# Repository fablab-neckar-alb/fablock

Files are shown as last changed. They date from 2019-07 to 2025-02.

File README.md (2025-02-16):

# Fablock

This is the software for a door-locking controller featuring a pin-pad for
authorization entry, a beep speaker for feedback, a motor locking/unlocking
 the door, two sensors detecting door closing and successful locking and
 a USART uplink to higher-level authentication logic living on a raspberry pi.

## Configurations

There are several instaces for this procect.
Configure the instance in the makefile:

* Upper
    This is the door to the bikeworkshop.
    Enable it by specifying CONFIG=UPPER
* Demo Board
    This is the configuration for the evaluation setup.
    Enable it by specifying CONFIG=DEMO
* Cellar
    This is the door to the Cellar door.
    Enable it by specifying CONFIG=CELLAR
* Social Room
    This is the placeholder for configuration for the Social Room.
    Enable it by specifying CONFIG=SOCIAL

## lockserver

Included is also the higher-level daemon in lockserver/ and the openscad files
 for the pin-pad casing.

## statustool

Small statustool that decodes the output from the serial port of the arduino

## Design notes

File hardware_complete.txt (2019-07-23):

pinpad:

  external wiring:

    *===* (pin header)
    |   | 
    |   +-------------------+
    |                       | 
    *=R2'=*=R3'=*=R4'===Rn'=* (female header / connector)

    Ri' = (0, 1k, 1.2k, 1.5k, 1.8k, 4.7k/2, 3.3k, 4.7k, 6.8k, 10k, 22k, 68k)

  internal wiring (4x3 daughter board):

    VCC-----*-Ru---+------+---+
                   |      |   |
                   Rm     |   |
                   |      |   |
    Pin_C4--*------+     ^Dz  *--Keypad_1(+)
                   |      |
                   C_pinp |
                   |      |
    GND-----*-Rd---+------+---*--Keypad_2(-)

    Ru     = 10k
    Rd     = 1k
    Rm     = 10k
    C_pinp = 2*220nF
    Dz     = 12V zener diode (better: 5.6V zener diode (TODO)),
    (everything in SMD parts except for Dz).

            +----+----+----+----+
            | *  |              |
            |GND Rd      Dz     |
            +----+----+-||-+----+
            | *       |      *  |
            |P_C4   C_pinp   K- |
            +----+-Rm-+----+----+
            | *  |       Dz  *  |
            |VCC Ru          K+ |
            +----+----+----+----+

main:

       Motor    Door Switch
    GND VDD PWM VCC-PIN-GND
     |   |   |   |   |   |
red ======================
cable
                            Keypad  Speaker Lock Switch
                            (+) (-) PIN GND PIN GND
                             |   |   |   |   |   |
yellow ===========================================
cable

Door_Switch Lock_Switch
     |          |
 C2--+      C3--+
     |          |
    C_sw       C_sw
     |          |
GND--+----------+

// B5---onboard LED circuit--GND

VCC---+--------------+
      |              |
      R_motor        C_sense
      |              |
  VDD-+----R_sense---+--------SENSE(C7)
      |
      Motor-------------------servo_pwm(C0)
      |
GND---+

C5----speaker---GND

VCC---C_vcc---GND

currently found a better zener diode:
  Keypad_1---<Dz'---Keypad_2

Dz' = 5.6V zener diode
R_motor = 5.6 Ohm
R_sense = 1.5 MOhm
C_sense = 0.47 uF
C_vcc = 470 uF

C_sw = 0.47 uF

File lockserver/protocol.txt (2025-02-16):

Communication with the lockserver:
send datagrams to /run/lockserver.sock with send()
if you want a reply, bind your socket first.

a message is a string, the first word of which is a command: "command args". Optionally terminated with a line feed.

Commands starting with a "." are processed by the daemon. Commands starting with a "!" are forwarded to the microcontroller.

The commands are (see $valid_request):
.register <events>...
  registers the sender for a list of event types. The registration times out after 1 hour. This request is idempotent.
  events:
    log_debug, log_notice, log_warning, log_error: get log messages
    W, R: get lines written to/read from the device
    challenge: get challenge messages
      a challenge consists of "0001", 4 salt digits and the user pin.
      The challenge message contains "challenge <salt> <userid>" for a valid
      challenge and "challenge FAIL" for an invalid challenge.

.unregister <events>...
  unregisters from the given events.

.baudrate <rate>
  changes the baudrate on server and device.

.close <requester>
  closes the door (forcefully) for <requester> subsystem.

.open <requester>
  opens the door (unconditionally) for <requester> subsystem.

.openfor <requester> <userid> <check_permission>
  opens the door for user <userid>, requested by subsystem <requester>.
  if <check_permission> is nonzero, the userid will be checked for
  existence and permission.
  replies with "openfor <userid> <valid>".
  <valid> is nonzero iff the request was fulfilled.

.pinentry <pin>
  simulates the entry of a pin.

.state
  requests the state of the door. The reply is "state <locked?1:0> <closed?1:0> <opening?2:closing?1:0> <status-info?2:succeeded?1:0>".

.reset_device
  resets the device.

(?<param>(?: \w+)*)$/;

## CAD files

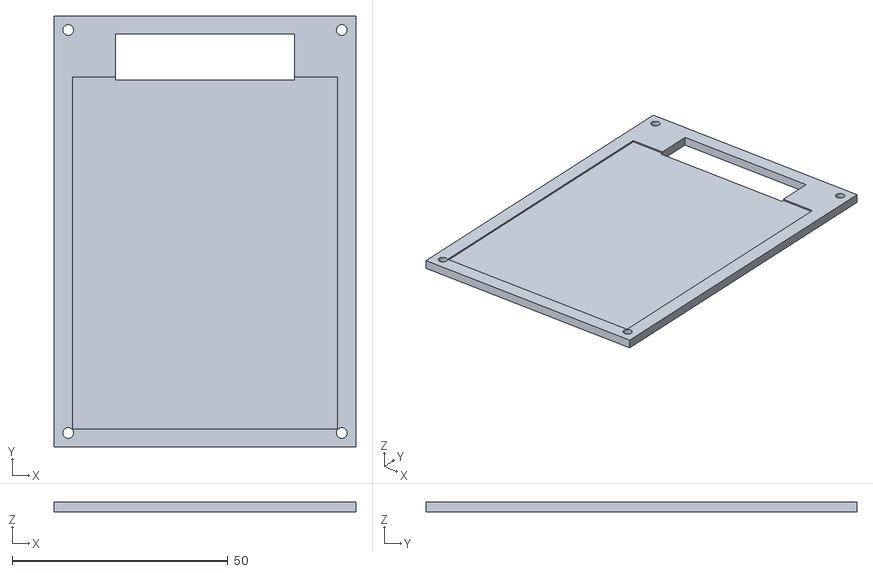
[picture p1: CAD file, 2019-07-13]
cad/pinpad-case-stl/rest.stl
70.0 x 100.0 x 2.40

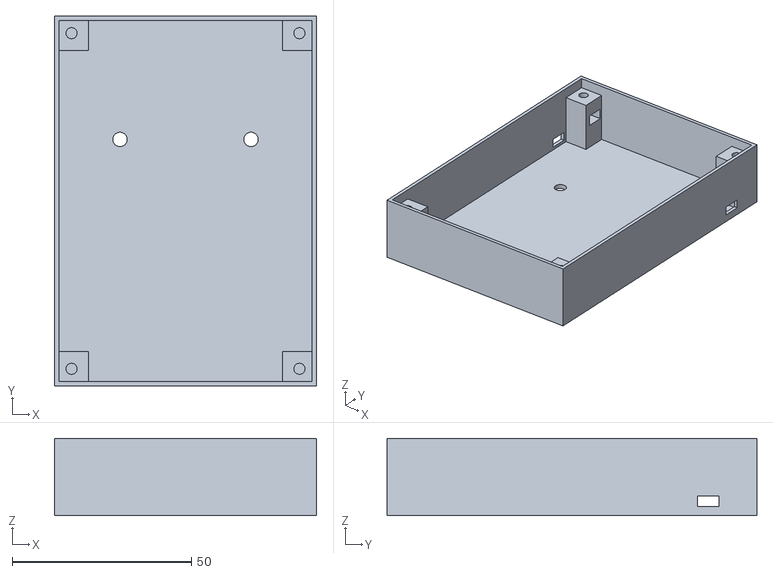
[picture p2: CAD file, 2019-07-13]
cad/pinpad-case-stl/box.stl
73.0 x 103.0 x 21.5

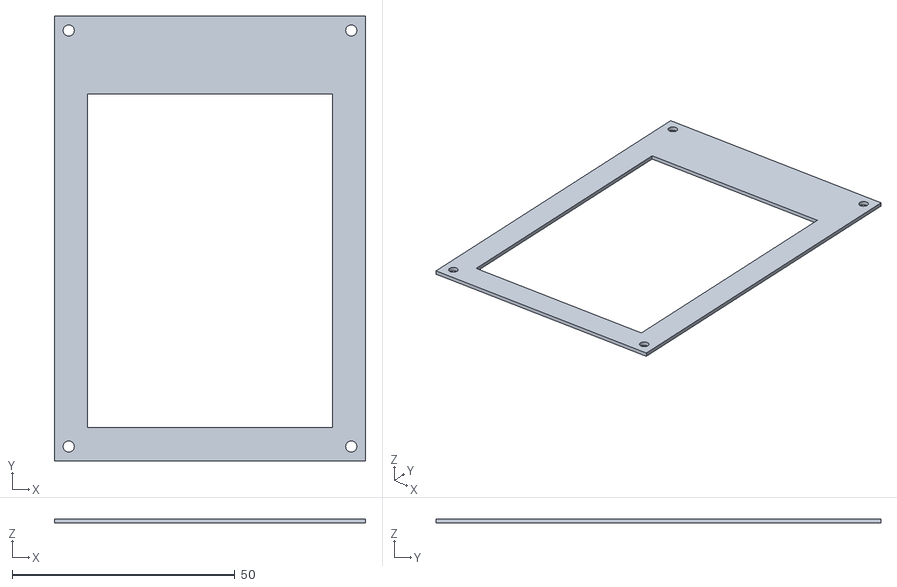
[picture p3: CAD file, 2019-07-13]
cad/pinpad-case-stl/lid.stl
70.0 x 100.0 x 1.00

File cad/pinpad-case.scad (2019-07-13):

include <utilities.scad>;

/*
  Copyright (c) 2019 by Thomas Kremer
  License: GNU GPL ver. 2 or 3
*/

/* PARTS LIST:
  box:  box();
  rest: rest();
  lid:  lid();
*/
demo = !currently_building;
hires = !demo;
$fn = hires ? 120 : 60;

pinpad_w = 61;
pinpad_h = 81;
pinpad_d = 0.4;
pinpad_bus_w = 41;
pinpad_bus_l_top = 10;
pinpad_bus_l = 51;
pinpad_border_w = 4;
pinpad_buttons_d = 2;

cable_r = 2;
cable_size = [6,3];

pinpad_x = 6;
pinpad_y = pinpad_x;
wall_d = 1.5;
bottom_d = wall_d;
lid_d = 1;
rest_d = 2;
box_d = 2*pinpad_bus_l_top+bottom_d;

box_size=[pinpad_w+2*pinpad_x,pinpad_h+2*pinpad_x+pinpad_bus_l_top,box_d];
  
lid_z = box_size[2]-lid_d;
pinpad_z = lid_z-pinpad_d;
rest_z = pinpad_z-rest_d;

// screw = [r, h, head_r, head_h]
screw = [2.5/2,18+1,5/2,1.5];
// nut = [w,h]
nut = [5,2+1]; // want extra space for nut because it's a bridging print.

box_screw_r = 4/2;

// align our screw boxes with the outside of the case.
// The screws are basically right outside the pinpad.
screw_box_w = (pinpad_x-screw[0])*2;

screws = [for (y=[-1,1],x=[-1,1])
            [box_size[0]/2,box_size[1]/2,0]+
            [x*box_size[0]/2,y*box_size[1]/2,atan2(0,x)]
            -screw_box_w/2*[x,y,0]];
//            -(pinpad_x-screw[0])*[x,y,0]];

box_screws = [for (x=[-1,1]) [(x+2)*box_size[0]/4,box_size[1]*2/3]];

// TODO: get the screw hole module into utilities.scad
module screw_hole(screw_r=3/2, screw_h=10, head_r=3, nut_w=5, nut_h=2, nut_z=2, depth=false, head_z=false, with_nut = false, screw=false, nut=false, infty = 100, extend=0, diaphragm_up=false, diaphragm_down=false, diaphragm_h = 0.3) {
  screw_r = screw != false ? screw[0] : screw_r;
  screw_h = screw != false ? screw[1] : screw_h;
  head_r = screw != false ? screw[2] : head_r;
  //head_h = screw != false ? screw[3] : head_h;
  nut_w = nut != false ? nut[0] : nut_w;
  nut_h = nut != false ? nut[1] : nut_h;
  with_nut = nut != false ? true : with_nut;

  //nut_z = depth != false ? nut_z+depth : nut_z;
  z = depth != false ? -depth : head_z != false ? head_z-screw_h : 0;
  nut_r = nut_w/sqrt(3);
  offs = extend;
  difference() {
    translate([0,0,z-offs])
      cylinder(r=screw_r+offs,h=screw_h+1);
    if (diaphragm_up) {
      translate([0,0,nut_z+nut_h+offs])
        cylinder(r=screw_r+offs+1,h=diaphragm_h);
    }
    if (diaphragm_down) {
      translate([0,0,nut_z-offs-diaphragm_h])
        cylinder(r=screw_r+offs+1,h=diaphragm_h);
      translate([0,0,z+screw_h-offs-diaphragm_h])
        cylinder(r=screw_r+offs+1,h=diaphragm_h);
    }
  }
  translate([0,0,z+screw_h-offs])
    cylinder(r=head_r+offs,h=infty-screw_h+2*offs);
  if (with_nut)
    translate([-nut_w/2,-nut_r,nut_z]-[1,1,1]*offs)
      cube([nut_w,nut_r+infty,nut_h]+[2,2,2]*offs);
}


module pinpad_hw() {
  eps = 0.01;
  color([0.7,0.7,0.7])
  linear_extrude(height=pinpad_d) {
    square([pinpad_w,pinpad_h]);
    translate([pinpad_w/2-pinpad_bus_w/2,pinpad_bus_l_top])
      square([pinpad_bus_w,pinpad_h]);
  }
  color([0.5,0.5,0.5])
  translate([pinpad_border_w,pinpad_border_w,eps])
    linear_extrude(height=pinpad_buttons_d-eps) {
      square([pinpad_w,pinpad_h]-[2,2]*pinpad_border_w);
  }
}

module box() {
  //screw_box_w = nut[0]+3*wall_d;//2*screw[0]+wall_d;
  //screw_box_w = screw_box_w+0.1;
  difference() {
    cube(box_size);
    difference() {
      translate([1,1,0]*(wall_d-slide_backlash)+[0,0,bottom_d])
        cube(box_size-[2,2,0]*(wall_d-slide_backlash));
      for (p2=screws,p=[[p2[0],p2[1],0]],ang=[p2[2]]) {
        difference() {
          translate(p-[1,1]*screw_box_w/2)
            cube([1,1,0]*screw_box_w+[0,0,rest_z]);
          translate(p)
            rotate([0,0,ang+90])
              screw_hole(screw=screw,nut=nut,head_z=box_size[2],nut_z=10,infty=50,diaphragm_up=true,extend=slide_backlash);
        }
      }
    }
    for (p=box_screws) {
      translate([p[0],p[1],-1])
        cylinder(r=box_screw_r,h=2+bottom_d);
    }
    translate([-1,box_size[1]-screw_box_w-cable_size[0]-1,bottom_d+1])
      cube([2+box_size[0],cable_size[0],cable_size[1]]);
    /*translate([-1,box_size[1]-screw_box_w-cable_r-1,bottom_d+cable_r+1])
      rotate([0,90,0])
        cylinder(r=cable_r,h=2+box_size[0]);*/
  }
}

module rest() {
  clearance = slide_backlash;
  union() {
    for (i=[0,1])
      linear_extrude(height=i?rest_d+pinpad_d:rest_d) difference() {
        square([box_size[0]-2*wall_d,box_size[1]-2*wall_d]);
        if (i)
          translate([1,1]*(pinpad_x-wall_d-clearance))
            square([pinpad_w,pinpad_h]+[2,2]*clearance);
        translate([pinpad_w/2-pinpad_bus_w/2,pinpad_h]+[1,1]*(pinpad_x-wall_d-clearance))
          square([pinpad_bus_w,pinpad_bus_l_top]+[2,2]*clearance);
        for (p2=screws,p=[[p2[0],p2[1]]]) {
          translate(p-[1,1]*wall_d)
            circle(screw[0]);
        }
      }
  }
}

module lid() {
  linear_extrude(height=lid_d) difference() {
    square([box_size[0]-2*wall_d,box_size[1]-2*wall_d]);
    translate([1,1]*(pinpad_x-wall_d+pinpad_border_w-1))
      square([pinpad_w,pinpad_h]-[2,2]*(pinpad_border_w-1));
    for (p2=screws,p=[[p2[0],p2[1]]]) {
      translate(p-[1,1]*wall_d)
        circle(screw[0]);
    }
  }
}

module case() {
  box();
  translate([wall_d,wall_d,rest_z])
    rest();
  translate([pinpad_x,pinpad_y,pinpad_z])
    pinpad_hw();
  translate([wall_d,wall_d,lid_z])
    lid();
}

if (demo) {
  //pinpad_hw();
  translate([-box_size[0]/2,-box_size[1]/2,0])
    case();
}

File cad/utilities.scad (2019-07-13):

/*
  Copyright (c) 2015-2017 by Thomas Kremer
  License: GNU GPL ver. 2 or 3
*/

no_virtuals = false;

// === fitting and friction avoiding constants ===

/*
  tests suggest the following:
  - cylinders of radii < 1 are fragile and easily broken.
  - the printer seems to constantly print 0.05mm more than specified, sometimes 0.1, sometimes even 0.0. (v=70mm/s, dz=0.2mm, T=220 deg, yellow filament TODO: diameter?)
  - consequently, holes are actually 2x0.05mm too small.
  - This also applies to vertical holes.
  - vertical axes in vertical holes are easily broken in assembly due to
     layered structure. But go smoothly.
  - 0.05 does no good. Maybe for hammering nails...
  - 0.1 sticks. Still need a hammer.
  - 0.15 sticks. Horizontal sliding possible. Vertical sliding sometimes difficult.
  - 0.2 fits and slides. Vertical sliding still a little rough.
  - 0.25 slides better.
  - gears go fine without backlash.
  - rafts are between a pain and impossible to remove.
  - small supports are also a pain to remove.
  - consider printing sliding gear axes horizontally (separately if necessary).
  - floating not measured. Consider one print layer (->0.2).
  - resting not measured. Consider half a print layer (->0.1) or postprocessing.
  - actually, printing 1mm radius holes stick well on 1mm radius real motors.
*/
rest_backlash  = 0.1;  // for accurately stacking objects onto each other
stick_backlash = 0.15; // for firmly sticking objects into holes
fit_backlash   = 0.25;  // for removably fitting objects into holes
slide_backlash = 0.3; // for objects gliding along other objects
float_backlash = 0.35;  // minimum distance for avoiding friction
gear_backlash  = 0.05;  // backlash for gears toward each other

/*
rest_backlash  = 0.1;  // for accurately stacking objects onto each other
stick_backlash = 0.15; // for firmly sticking objects into holes
fit_backlash   = 0.2;  // for removably fitting objects into holes
slide_backlash = 0.25; // for objects gliding along other objects
float_backlash = 0.3;  // minimum distance for avoiding friction
gear_backlash  = 0.0;  // backlash for gears toward each other
*/

amlaser_radius = 0.095; // radius of laser beam of laser cutter


// === for our external build system (used for e.g. splinecyl) ===

// the external build system will override this variable. To have code that
// checks it work outside of the build system, we need to initialize it.
currently_built_part = undef;
currently_building = currently_built_part != undef;

module part(name) {
  if (currently_built_part == name)
    children();
}

module demo() {
  if (!currently_building)
    children();
}

// === helper functions and constants ===

pi=3.1415926535897932384626433832795;
mat_2d_to_3d = [[1,0],[0,1],[0,0]];

function turn_matrix(v=[0,0,0],x=false,y=false,z=false) =
 x!=false?[[1,0,0],[0,cos(x),-sin(x)],[0,sin(x),cos(x)]]:
 y!=false?[[cos(y),0,sin(y)],[0,1,0],[-sin(y),0,cos(y)]]:
 z!=false?[[cos(z),-sin(z),0],[sin(z),cos(z),0],[0,0,1]]:
 turn_matrix(z=v[2])*
 turn_matrix(y=v[1])*
 turn_matrix(x=v[0]);

/*
    ^ w'
  -_ \  ^ v
    -_\/      
   <--+-_     
   w     -_
  w = m*v + n*w2, w2*v = 0
  w' = -m*v + n*w2 = w-2*m*v
  m*v = (v*w)/(|v|^2)*v = (v*w)/(v*v)*v
  w' = w-2*(v*w)/(v*v)*v
  M = id - v*v^t*2/(v*v) = id - [[v[0]],[v[1]],[v[2]]]*[v]*2/(v*v)
*/
function mirror_matrix(v=[0,0,1]) =
    [[1,0,0],[0,1,0],[0,0,1]] - [[v[0]],[v[1]],[v[2]]]*[v]*2/(v*v);

// normal,line vector, line source point (plane is in center)
// result is the intersection point.
// x: x*n = 0, x-p = m*v;
// (p+m*v)*n = 0; p*n + m*(v*n) = 0; m = -(p*n)/(v*n); (v*n != 0)
function plane_intersect(n,v,p) = p-(p*n)/(v*n)*v;

/*
  intersection of two circles:

 (x-gx_a)^2+y^2 = gsh_b^2, (x-g1_pos[0])^2+(y-g1_pos[1])^2 = gsh_a^2

  (x-x0)^2+(y-y0)^2 = r0^2,
  (x-x1)^2+(y-y1)^2 = r1^2

  (x-x0)^2-(x-x1)^2+(y-y0)^2-(y-y1)^2 = r0^2-r1^2,
  x0^2-x1^2-2x(x0-x1)+y0^2-y1^2-2y(y0-y1) = r0^2-r1^2,
  2x(x0-x1)+2y(y0-y1) = -r0^2+r1^2+x0^2+y0^2-x1^2-y1^2 = 2*C,
  y = (C-x(x0-x1))/(y0-y1),

  (x-x0)^2+((C-x(x0-x1))/(y0-y1)-y0)^2 = r0^2,
  x^2-2*x*x0+x0^2+(C^2-2Cx(x0-x1)+x^2(x0-x1)^2)/(y0-y1)^2-2*(C-x(x0-x1))/(y0-y1)*y0 + y0^2 = r0^2,
  x^2*(y0-y1)^2-2*x*x0*(y0-y1)^2+C^2-2Cx(x0-x1)+x^2(x0-x1)^2-2*(C-x(x0-x1))*(y0-y1)*y0 + (x0^2+y0^2-r0^2)*(y0-y1)^2 = 0,
  x^2*(y0-y1)^2 -2*x*x0*(y0-y1)^2 +C^2 -2Cx(x0-x1) +x^2(x0-x1)^2 -2*C*(y0-y1)*y0 +2*x(x0-x1)*(y0-y1)*y0 + (x0^2+y0^2-r0^2)*(y0-y1)^2 = 0,
  x^2*(y0-y1)^2 +x^2(x0-x1)^2 -2*x*x0*(y0-y1)^2 -2Cx(x0-x1) +2*x(x0-x1)*(y0-y1)*y0  +C^2 -2*C*(y0-y1)*y0 +(x0^2+y0^2-r0^2)*(y0-y1)^2 = 0,
  x^2*((y0-y1)^2+(x0-x1)^2) +x*(-2*x0*(y0-y1)^2 -2C(x0-x1) +2*(x0-x1)*(y0-y1)*y0)  +C^2 -2*C*(y0-y1)*y0 +(x0^2+y0^2-r0^2)*(y0-y1)^2 = 0,

  a = ((y0-y1)^2+(x0-x1)^2)
  b = 2*(-x0*(y0-y1)^2 -C(x0-x1) +(x0-x1)*(y0-y1)*y0)
  c = C^2 -2*C*(y0-y1)*y0 +(x0^2+y0^2-r0^2)*(y0-y1)^2,

  x = -b+-sqrt(b^2-4ac)/(2*a)

*/

function quadratic_solutions(a,b,c) =
  [(-b+sqrt(b*b-4*a*c))/(2*a),(-b-sqrt(b*b-4*a*c))/(2*a)];

function circles_intersections_helper2(x0,y0,r0,x1,y1,r1,C,x) =
  [[x[0],(C-x[0]*(x0-x1))/(y0-y1)],[x[1],(C-x[1]*(x0-x1))/(y0-y1)]];

function circles_intersections_helper(x0,y0,r0,x1,y1,r1,C) =
  circles_intersections_helper2(x0,y0,r0,x1,y1,r1,C,
    x = quadratic_solutions(
      a = (pow(y0-y1,2)+pow(x0-x1,2)),
      b = 2*(-x0*pow(y0-y1,2) -C*(x0-x1) +(x0-x1)*(y0-y1)*y0),
      c = pow(C,2) -2*C*(y0-y1)*y0 +(pow(x0,2)+pow(y0,2)-pow(r0,2))*pow(y0-y1,2)
    )
  );
function circles_intersections(p1,r1,p2,r2) =
  circles_intersections_helper(p1[0],p1[1],r1,p2[0],p2[1],r2,
    C = (p1*p1-p2*p2-r1*r1+r2*r2)/2
  );


function turn_to_vector(v,v3=false,v10=false,v11=false,v1=false,v2=false) =
  v3 == false ? turn_to_vector(v,v/norm(v)) :
  v10 == false ? turn_to_vector(v,v3,cross(v3,[0,0,1])) :
  v11 == false ? turn_to_vector(v,v3,v10,norm(v10) < 0.5 ? cross(v3,[0,1,0]) : v10) :
  v1 == false ? turn_to_vector(v,v3,v10,v11,v11/norm(v11)) :
  v2 == false ? turn_to_vector(v,v3,v10,v11,v1,cross(v1,v3)) :
    [[v1[0],v2[0],v3[0],0],
     [v1[1],v2[1],v3[1],0],
     [v1[2],v2[2],v3[2],0],
     [0,0,0,1]];


// === spline stuff ===

module cyl(p1=[0,0,0],p2=false,r=1,r1=false,r2=false,$fn=$fn) {
  two_point = p2!=false;
  p2 = two_point?p2-p1:p1;
  p1 = two_point?p1:[0,0,0];
  r1 = r1!=false?r1:r;
  r2 = r2!=false?r2:r;
  h = norm(p2);

  v3 = p2/norm(p2);
  v10 = cross(v3,[0,0,1]);
  v11 = norm(v10) < 0.5 ? cross(v3,[0,1,0]) : v10; // norm==sin(v3,e3)
  // norm at least 1/2 now (could be squeezed to 1/sqrt(2))
  v1 = v11/norm(v11);
  v2 = cross(v1,v3);

  // needs to map e3 to p2 and be orthogonal.
  mat = [[v1[0],v2[0],v3[0],0],
         [v1[1],v2[1],v3[1],0],
         [v1[2],v2[2],v3[2],0],
         [0,0,0,1]];

  translate(p1)
    multmatrix(mat)
      cylinder(r1=r1,r2=r2,h=h,$fn=$fn);
}

// c is an array of 4 control points, 0 <= t <= 1. dc and d2c are internal.
function bezier_eval(c,t,dc=false,d2c=false) = 
  dc == false ? bezier_eval(c,t,
    [c[0]*(1-t)+c[1]*t,c[1]*(1-t)+c[2]*t,c[2]*(1-t)+c[3]*t]) :
  d2c == false ? bezier_eval(c,t,dc,
    [dc[0]*(1-t)+dc[1]*t,dc[1]*(1-t)+dc[2]*t]) :
  d2c[0]*(1-t)+d2c[1]*t;  

// spline is an array of 3*N+1 control points, t arbitrary. ix is internal.
function bezier_spline_eval(spline,t,ix=false) = 
  ix == false ?
    t <= 0 ? spline[0] :
    t >= floor((len(spline)-1)/3) ? spline[len(spline)-1] :
    bezier_spline_eval(spline,t-floor(t),floor(t)*3) :
  bezier_eval([spline[ix],spline[ix+1],spline[ix+2],spline[ix+3]],t);

// cylinder from p1 to p2, cut to fit cylinders from p0 to p1 and p2 to p3.
// needed for polycyl and splinecyl.
// In extreme cases, a sphere part is injected. (extreme = angles above 20 deg)
module polycyl_part(p0,p1,p2,p3,r) {
  /*
     ______/    ______.
     _____/\    ___/-^
         /\ \     / /
           \     / /

    FIXED: a lot of nans.
  */
  r0 = len(p1) >= 4 ? p1[3]*r : r;
  r1 = len(p2) >= 4 ? p2[3]*r : r;
  p03 = [p0[0],p0[1],p0[2]];
  p13 = [p1[0],p1[1],p1[2]];
  p23 = [p2[0],p2[1],p2[2]];
  p33 = [p3[0],p3[1],p3[2]];
  p1 = p13;
  p2 = p23;
  at_start = p0 == false;
  at_end   = p3 == false;
  p0 = (p0 == false || p03 == p13) ? p1*2-p2 : p03;
  p3 = (p3 == false || p33 == p23) ? p2*2-p1 : p33;
  dp0 = p1-p0;
  dp  = p2-p1;
  dp1 = p3-p2;
  c0 = (dp0*dp)/(norm(dp0)*norm(dp));
  c1 = (dp*dp1)/(norm(dp)*norm(dp1));
  cosa = c0 > 0.99 ? 1 : c0;
  cosb = c1 > 0.99 ? 1 : c1;
  ds0 = min(norm(dp),norm(dp0))/4;
  ds1 = min(norm(dp),norm(dp1))/4;
/*
  a2 = acos(cosa)/2;
  b2 = acos(cosb)/2;
*/
  v0 = cross(dp0,dp)/(norm(dp0)*norm(dp));
  v1 = cross(dp,dp1)/(norm(dp)*norm(dp1));
  sina = norm(v0);
  sinb = norm(v1);
  a = cosa > 0.5 ? asin(sina) : acos(cosa);
  b = cosb > 0.5 ? asin(sinb) : acos(cosb);
/*
  a2 = asin(sina)/2;
  b2 = asin(sinb)/2;
*/
  a2 = a/2;
  b2 = b/2;
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

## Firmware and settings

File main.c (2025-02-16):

// for spi.h
#define NO_LUFA

#ifdef CONFIG_DEMO
  #include "demodoor.h"
#elif CONFIG_UPPER
  #include "oben.h"
#elif CONFIG_CELLAR
  #include "cellar.h"
#elif CONFIG_SOCIAL
  #include "sozialraum.h"
#else
  #error "Unset Config"
#endif

//#define DEBUG_DISPLAY
#define DEBUG_MOTOR_SENSE
//#define DEBUG_INTERRUPTS
#define ENABLE_EASTEREGGS
//#define ENABLE_COPYRIGHTED_EASTEREGGS


#include <avr/io.h>
#include <avr/sleep.h>
#include <avr/power.h>
#include <avr/wdt.h>
#include <util/atomic.h>
#include <util/delay.h>
#include <string.h>
#include <stdlib.h>
#include <stdbool.h>
#include <math.h>

#include <timers.h>
#define EVENT_QUEUE_SIZE 8
#include <events.c.h>


  
#define TIMER_DIV 1
#define TIMER_SCALE TIMER_SCALE_1
//#define TIMER_DIV 1024
//#define TIMER_SCALE TIMER_SCALE_DIV_1024

// was used for morse code:
#define shortdelay msec2ticks(200.0,TIMER_DIV)
#define longdelay msec2ticks(800.0,TIMER_DIV)

/*
#define EEPROMFS_VARS 2
#include "eeprom.h"
eepromfs_index_t eep_index;
*/
//#define eep_segment_low 0
//#define eep_segment_high 1

#define ledpin 5
#define baudrate 9600
//#define baudrate 57600
//#define baudrate 19200
// 9600 19200 38400 57600 115200

// can have baudrates of up to 2000000 (usable!)

// some defines used by the last LUFA project, parts of which were included.
#define LEDS_LED1 (1<<ledpin)
#define LEDs_ToggleLEDs(mask) PINB = mask
#define LEDs_GetLEDs() (PORTB & LEDS_LED1)
#define LEDs_TurnOnLEDs(mask) PORTB |= mask
#define LEDs_TurnOffLEDs(mask) PORTB &= ~mask
#define ATTR_NO_INIT __attribute__((section(".noinit")))
#define ATTR_ALWAYS_INLINE __attribute__((always_inline))

#define outbuf_size 80
#include <usart.h>

//#define ADCW_READ_COUNT (1 << 6)
#define ADCW_READ_COUNT (1 << 5)

#include <adc.h>
#include <adc_watch.h>
//#include "spi.h"
#include "prng.h"

#ifdef DEBUG_DISPLAY
#include <pcd8544_display.h>
#include "testfont.h"
#endif


#include "beep.h"
//#define MELODY_DEFINE_KOROBEINIKI
#include "melody.h"
#include "adnauseam.h"
#include "korobeiniki.h"

#ifdef ENABLE_COPYRIGHTED_EASTEREGGS
#include "la_prapoutische.h"
#include "mccarthys_waltz.h"
#endif

#include <pinpad.h>

//#define DOOR_MOTOR_IS_STEPPER
#define DOOR_MOTOR_IS_DC
#define DOOR_MOTOR_TIMER_DIV 64
#define DOOR_MOTOR_OC 0


#include "door.h"

/*

  note: space for bolt detector is 15 x 20 x 35 mm^3

  door layout:

  <---------- 140 ------------> 
   .........3......6...II....   ^
   .  +----------*-+----*-+ .   |
   .  |<--- 90 --->|      | .   |
   .  |            |      | .   110
   .  |            |      | .   |
   .  |        --- |      | 5   |
   ...|.....3... * |*.3...|..   v
      |            |   *  |


       Motor    Door Switch
    GND VDD PWM VCC-PIN-GND
     |   |   |   |   |   |
red ======================
cable
                            Keypad  Speaker Lock Switch
                            (+) (-) PIN GND PIN GND
                             |   |   |   |   |   |
yellow ===========================================
cable

*/

void process_char(char c);
void process_pinpad_char(char c);

static char hexchar(uint8_t i) {
  return i < 10 ? '0'+i : i < 16 ? 'A'-10+i : 'X';
}

void buftohex(const uint8_t* src, char* dest, int count) {
  for (int i = 0; i < count; i++) {
    uint8_t val = src[i];
    dest[2*i] = hexchar(val >> 4);
    dest[2*i+1] = hexchar(val & 15);
  }
  dest[2*count] = 0;
}

void inttohex(uint32_t value, char* dest, int count) {
  for (int i = 0; i < count; i++) {
    uint8_t val = (value & 0xf);
    value >>= 4;
    dest[count-1-i] = hexchar(val);
  }
  dest[count] = 0;
}

uint32_t hex2int(const char* s) {
  uint32_t res = 0;
  for (int i = 0; s[i] != 0 && i < 20; i++) {
    char c = s[i];
    char v = c-'0';
    if (v > 9) v = c-'A'+10;
    if (v > 15) v = c-'a'+10;
    if (v > 15 || v < 0) v = 0;
    res <<= 4;
    res |= v;
  }
  return res;
}

bool snprintl(char* s, int len, int32_t value) {
  bool positive = value >= 0;
  bool ok = 1;
  uint32_t val;
/*  if (!positive) {
    val = -value;
  }*/
  if (positive) {
    val = value;
  } else {
    val = (uint32_t)(-value);
  }
  int i = 0;
  while (i < len && val != 0) {
    char v0 = val % 10;
    val /= 10;
    s[len-1-i] = '0'+v0;
    i++;
  }
  if (i == 0) {
    s[len-1] = '0';
    i++;
  }
  if (!positive) {
    if (i == len-1) {
      i--;
      ok = 0;
    }
    s[len-1-i] = '-';
  }
  if (val != 0) {
    ok = 0;
  }
  while (i < len) {
    s[len-1-i] = ' ';
    i++;
  }
  return ok;
}

// --- power management ---

void poweroff() {
  cli();
  events_clear();
  PORTB &= ~(1<<ledpin);
  while(true) {
    // disable interrupts
    cli();
    // disable watchdog
    wdt_reset();
    MCUSR &= ~(1 << WDRF);
    wdt_disable();
    // disable Analog Comparator (to make sure that internal AREF is not used)
    ACSR = 1 << ACD;
    // disable ADC (ref. says "The ADC must be disabled before shutdown")
    // also disable all digital input buffers on ADC pins. Should happen
    // automatically anyway, but better to be explicit.
    adc_conf(false,0xff,0);
    // shut down all peripherals
    power_all_disable();
    // go to sleep
    set_sleep_mode(SLEEP_MODE_PWR_DOWN);
    sleep_enable();
    sleep_bod_disable();
    sleep_cpu();
    // should not be reached. But who knows for sure?
    PORTB |= 1<<ledpin; // If something wrong, at least notify the user...
  }
}

// --- application ---


// The device loads a saved state at bootup and maybe later again.
// It saves a state when requested by the user.
// Currently a no-op because we don't actually have any state.

void save_state() {
}

void load_state() {
}

// The LED is sadly placed on SCK, so we don't use it right now.
void led_blink_event(void* param) {
  LEDs_ToggleLEDs(LEDS_LED1);

  int16_t i = (int16_t)param;

  if (i > 0) {
    i--;
    enqueue_event_rel(msec2ticks(250,TIMER_DIV),&led_blink_event,(void*)i);
  }
}

/*
//void EVENT_beep_done() {
void EVENT_melody_done() {
  // nothing for now.
}
*/

void EVENT_softosc_done(uint8_t channel) {
  if (channel == BEEP_CHANNEL)
    EVENT_beep_done();
}


// we use a melody structure so that we can make more complicated feedback sounds in the future. However we must keep track of the starting notes' indexes in the index array below.
melody_begin(feedback_melody,480)
  // 0, sleep (0)
  melody_note(c,-1,1)
  melody_note(b,-2,1)
  melody_note(a,-2,8)
  melody_stopmarker()
  // 4, bad (1)
  melody_note(a,-1,4)
  melody_stopmarker()
  // 6, good (2)
  melody_note(a,0,4)
  melody_stopmarker()
  // 8, start (3)
  melody_note(a,1,4)
  melody_stopmarker()
  // 10, end (4)
  melody_note(e,1,4)
  melody_stopmarker()
  // 12, wakeup (5)
  melody_note(a,2,4)
  melody_stopmarker()
  // 14, good pin (6)
  melody_note(a,0,2)
  melody_note(cis,1,2)
  melody_note(e,1,2)
  melody_note(a,1,3)
  melody_note(e,1,1)
  melody_note(a,1,4)
  melody_stopmarker()
  // 21, bad pin (7)
  melody_note(g,-1,3)
  melody_rest(1)
  melody_note(g,-1,3)
  melody_rest(1)
  melody_note(g,-1,8)
  melody_stopmarker()
  // 27, anything else (8)
  melody_note(a,0,8)
melody_end()

// sleep, bad, good, start, end, wakeup, good pin, bad pin, anything
static const uint8_t feedback_notes_ix[] PROGMEM = {0,4,6,8,10,12,14,21,27};
#define feedback_sounds_count (sizeof(feedback_notes_ix)/sizeof(feedback_notes_ix[0]))


void do_pinpad_feedback(int i) {
  i = i < feedback_sounds_count ? i : feedback_sounds_count-1;
  //melody_play(feedback_melody);
  melody_set_time_unit(melody_get_time_unit(&feedback_melody));
  uint8_t ix = pgm_read_byte(&feedback_notes_ix[i]);
  melody_play_notes(melody_get_notes(&feedback_melody)+ix);
}

#define inbuf_size 80
char inbuf[inbuf_size+1];
int inbuf_len = 0;

// This is ok:
//char* const inbuf_ptr PROGMEM = &inbuf[0];
#define pinpad_inbuf_size 32
char pinpad_inbuf[pinpad_inbuf_size+1];
int pinpad_inbuf_len = 0;

#define pinpad_timeout sec2ticks(10,TIMER_DIV)
bool pinpad_sleeping = false;

void pinpad_sleep_event(void* param) {
  pinpad_sleeping = true;
  pinpad_sleep();
  pinpad_inbuf_len = 0;
  do_pinpad_feedback(0);
  usart_msg("AWAKE=0\n");
}

void pinpad_be_used() {
  dequeue_events(&pinpad_sleep_event);
  enqueue_event_rel(pinpad_timeout,&pinpad_sleep_event,(void*)0);
}

void print_door_feedback(uint8_t mode, uint8_t success) {
  /*
    DOOR=$locked$closed${closing?1:opening?2}$succeeded\n
    (succeeded == fail?0:success?1:unfinished?2:-)
  */
  /*
  char msg[10] = "DOOR=....\n";
  msg[5] = door_is_locked()?'1':'0';
  msg[6] = door_is_closed()?'1':'0';
  msg[7] = mode+'0';
  msg[8] = success?'1':'0';
  usart_write(msg,10);
  */
  usart_msg("DOOR=");
  usart_writechar(door_is_locked()?'1':'0');
  usart_writechar(door_is_closed()?'1':'0');
  usart_writechar('0'+mode);
  usart_writechar('0'+success);
  usart_writechar('\n');
}

#define DOOR_REPORT_DELAY msec2ticks(200,TIMER_DIV)

void report_state_event(void* param) {
  print_door_feedback(door_mode, 2);
}

uint8_t recent_pins[3] = {0,0,0};
//int32_t last_keypress_time = 0;

void EVENT_Interrupt(uint8_t port, uint8_t pins) {
  // fill the entropy into the random buffer:
  uint32_t time = get_time();
  prng_write_byte(time & 0xff);

  uint8_t changedpins = pins ^ recent_pins[port];

  uint8_t door_imask = (1 << DOOR_SENSOR_PIN) | (1 << DOOR_BOLTSENSOR_PIN);

  if (port == 1) { // Port C
    if (pinpad_sleeping && (~pins & (1<<PINPAD_PIN))) {
      pinpad_sleeping = false;
      pinpad_unsleep();
      pinpad_be_used();
      do_pinpad_feedback(5);
      usart_msg("AWAKE=1\n");
    }
    if (changedpins & door_imask) {
      if (changedpins & (1 << DOOR_SENSOR_PIN))
        door_sensor_changed();
      if (changedpins & (1 << DOOR_BOLTSENSOR_PIN))
        door_boltsensor_changed();
      //print_door_feedback(0,success);
      dequeue_events(&report_state_event);
      enqueue_event_rel(DOOR_REPORT_DELAY,&report_state_event,NULL);
    }
  }
/*
  //  D6,D7,B0,B1: button ports, input (up,right,left,down)
  uint8_t mask = port == 0 ? 0x03 : port == 2 ? 0xc0 : 0;
  changedpins &= mask;
*/

  recent_pins[port] = pins;

#ifdef DEBUG_INTERRUPTS
  char msg[10] = "r0=......\n";
  msg[1] = '0'+port;
  inttohex(pins,&msg[3],2);
  msg[5] = '\n';
  msg[6] = 0;
  if (usart_writable_space() > 7) {
    usart_write(msg,6);
  }
#endif
}

ISR (PCINT0_vect, ISR_BLOCK)
{
  EVENT_Interrupt(0,PINB);
}

ISR (PCINT1_vect, ISR_BLOCK)
{
  EVENT_Interrupt(1,PINC);
}

ISR (PCINT2_vect, ISR_BLOCK)
{
  EVENT_Interrupt(2,PIND);
}

void setup_Interrupts(uint8_t maskB, uint8_t maskC, uint8_t maskD) {
  PCICR = ((maskB?1:0) << PCIE0)
        | ((maskC?1:0) << PCIE1)
        | ((maskD?1:0) << PCIE2);
  // PCIFR & (1<< PCIF0)
  PCMSK0 = maskB;
  PCMSK1 = maskC;
  PCMSK2 = maskD;
}
 
void buttons_init() {
  // enable pull-ups for B0,B1,D6,D7
  //PORTB |= 0x03;
  //PORTD |= 0xc0;
  
  uint8_t door_imask = (1 << DOOR_SENSOR_PIN) | (1 << DOOR_BOLTSENSOR_PIN);
  //setup_Interrupts(0x03,(1<<PINPAD_PIN) | door_imask,0xc0); // B0,B1,D6,D7
  setup_Interrupts(0x00,(1<<PINPAD_PIN) | door_imask,0x00);

  recent_pins[0] = PINB;
  recent_pins[1] = PINC;
  recent_pins[2] = PIND;
}

const char ok_msg[] PROGMEM = "OK.\n";
#define usart_ok() usart_write_P(ok_msg,sizeof(ok_msg)-1)

#define pinpad_debug_interval msec2ticks(100,TIMER_DIV)
void pinpad_debug_event(void* param) {
  int16_t value = adcw_state.values[PINPAD_PIN];
  char msg[5];
  snprintl(msg,4,value);
  msg[4] = 0;
#ifdef DEBUG_DISPLAY
  display_text(0,24,&testfont,msg);
#else
  usart_writechar('P');
  usart_write(msg,4);
  usart_writechar('\n');
#endif
  enqueue_event_rel(pinpad_debug_interval,&pinpad_debug_event,NULL);
}

void process_line() {
  char *s = inbuf;
  if (inbuf_len == 0)
    return;
  if (s[0] != '!') {
    // int len = inbuf_len;
    // we don't have any use for non-command data, so we just remind the user
    // to disable the tty's useless echo feature.
    usart_msg("!ECHO OFF\n");
  } else if (inbuf_len >= 2) {
    char cmd = s[1];
    char *param = &s[2];
    switch (cmd) {
      case '0': {
          // our protocol version. May also be used as a generic ping.
          usart_msg("VERSION 3\n");
        }
        break;
      case 'a': {
          // start/stop adnauseam playing.
          uint32_t do_play = hex2int(param);
          if (do_play) {
            adnauseam_play(korobeiniki_progression);
          } else {
            adnauseam_stop();
          }
        }
        break;
      case 'b': {
          // set a new baud rate. The user will have to adapt to get the OK.
          uint32_t baud = hex2int(param);
          usart_init_baud(baud);
          usart_ok();
        }
        break;
      case 'D': {
          // open/close the door.
          uint32_t open = hex2int(param);
          if (open)
            door_unlock();
          else
            door_lock();
          usart_ok();
        }
        break;
      case 'd': {
        // get current door state.
        dequeue_events(&report_state_event);
        enqueue_event_rel(DOOR_REPORT_DELAY,&report_state_event,NULL);
      }
      case 'f': {
          // blink the LED <param> times.
          LEDs_TurnOffLEDs(LEDS_LED1);
          uint16_t count = hex2int(param)*2-1;
          enqueue_event_rel(1,&led_blink_event,(void*)count);
        }
        break;
      case 'F': {
          // stop blinking the LED.
          // turn it on (param=1) or off (param=0) or leave it as it is (param=2)
          uint16_t stay = hex2int(param);
          dequeue_events(&led_blink_event);
          if (stay == 0) {
            LEDs_TurnOffLEDs(LEDS_LED1);
          } else if (stay == 1) {
            LEDs_TurnOnLEDs(LEDS_LED1);
          }
        }
        break;
      case 'G': {
          // read adc_watch channel <param>.
          uint8_t num = hex2int(param);
          usart_write(inbuf,inbuf_len);
          uint32_t value;
          value = adcw_state.values[num % 8];
          char msg[10];
          inttohex(value,msg,9);
          usart_writechar(' ');
          usart_write(msg,9);
          usart_writechar('\n');
        }
        break;
      case 'k':
        // play the korobeiniki main theme once.
        melody_play(&korobeiniki_a);
        break;
      case 'l':
        // currently a no-op.
        load_state();
        usart_ok();
        break;
      case 'm': {
          // play musical feedback sound <param>.
          uint32_t i = hex2int(param);
          do_pinpad_feedback(i);
        }
        break;
      case 'P': {
          // debug the pinpad by printing out adc readings.
          enqueue_event_rel(pinpad_debug_interval,&pinpad_debug_event,NULL);
          usart_ok();
        }
        break;
      case 's':
        // currently a no-op.
        save_state();
        usart_ok();
        break;
      case 't': {
          // beep with frequency <param> for half a second.
          uint16_t freq = hex2int(param);
          beep(freq,500);
        }
        break;
      case 'T': {
          // Get (up-)time. Use to verify that a reset has been done.
          uint32_t time = get_time();
          usart_msg("TIME=");
          char msg[9];
          inttohex(time,msg,8);
          usart_write(msg,8);
          usart_writechar('\n');
        }
        break;
      case 'z':
        // power down.
        poweroff();
        break;
    }
  }
}

void process_char(char c) {
  if (c == 10 || c == 13) {
    if (inbuf_len < inbuf_size) {
      inbuf[inbuf_len] = 0;
      process_line();
    }
    inbuf_len = 0;
  } else if (inbuf_len < inbuf_size) {
    if (c > 0x80 || c < 0x20) {
      inbuf_len = inbuf_size;
    } else {
      inbuf[inbuf_len] = c;
      inbuf_len++;
    }
  } // else ignore more characters and in the end the whole line.
}

void process_pinpad_line() {
  char *s = pinpad_inbuf;
  if (pinpad_inbuf_len == 0)
    return;

  // special single-digit codes (*X#).
  if (pinpad_inbuf_len == 1) {

    switch (pinpad_inbuf[0]) {
      // code to just lock the door: *0#
      case '0' :
        door_lock();
        //door_schedule_locking(sec2ticks(2,TIMER_DIV));
        return;
#ifdef ENABLE_EASTEREGGS
      // code to start music: *1#
      case '1' :
            adnauseam_play(korobeiniki_progression);
            return;
      // code to stop music: *2#
      case '2':
            adnauseam_stop();
            return;
#ifdef ENABLE_COPYRIGHTED_EASTEREGGS
      case '3':
            melody_play(&la_prapoutische);
            return;
      case '4':
            melody_play(&mccarthys_waltz);
            return;
#endif
#endif
      default:;
    }
  }
#ifdef DEBUG_BACKDOOR
  #warning(Backdoor Active)
  // TODO: remove this backdoor:
  if (strcmp(s,"12345") == 0) {
    door_unlock();
  }
#endif

#ifdef DEBUG_DISPLAY
  display_clear();
  display_text(0,8,&testfont,s);
#endif
  usart_msg("PIN=");
  usart_write(s,pinpad_inbuf_len);
  usart_msg("\n");
}

// TODO: beep accordingly
void process_pinpad_char(char c) {
  if (c == '#') {
    if (pinpad_inbuf_len < pinpad_inbuf_size) {
      pinpad_inbuf[pinpad_inbuf_len] = 0;
      process_pinpad_line();
    }
    pinpad_inbuf_len = 0;
    do_pinpad_feedback(4);
  } else if (c == '*') {
    pinpad_inbuf_len = 0;
    do_pinpad_feedback(3);
  } else if (pinpad_inbuf_len < pinpad_inbuf_size) {
    if (c > 0x80 || c < 0x20) {
      pinpad_inbuf_len = pinpad_inbuf_size;
    } else {
      pinpad_inbuf[pinpad_inbuf_len] = c;
      pinpad_inbuf_len++;
#ifdef DEBUG_DISPLAY
      if (pinpad_inbuf_len < pinpad_inbuf_size) {
        pinpad_inbuf[pinpad_inbuf_len] = 0;
        display_text(0,16,&testfont,pinpad_inbuf);
      }
#endif
      do_pinpad_feedback(2);
    }
  } // else ignore more characters and in the end the whole line.
}

void EVENT_USART_Read(char c) {
  // fill the entropy into the random buffer:
  prng_write_byte(get_time() & 0xff);

  process_char(c);
}

void EVENT_pinpad_keypressed(char c) {
  // fill the entropy into the random buffer:
  prng_write_byte(get_time() & 0xff);

  pinpad_be_used();
  if (c != 0)
    process_pinpad_char(c);
  else do_pinpad_feedback(1);
}

void EVENT_adc_watch(uint8_t channel, int16_t value) {
  if (channel == PINPAD_PIN) {
    pinpad_on_adc_read(value);
  } else if (channel == DOOR_MOTOR_SENSE_PIN) {
    door_on_motor_sense_read(value);
#ifdef DEBUG_MOTOR_SENSE
    char s[5];
    snprintl(s,4,value);
    s[4] = '\n';
    usart_msg("SENSE=");
    usart_write(s,5);
#endif
  } else {
    adc_watch_set_range(channel,value-2,value+2);
  }
}

/*
  1 = stall (before succeeding in whatever we're doing)
  2 = not running, but should
  3 = running, but should not
*/

void EVENT_door_motor_failing(uint8_t symptom) {
  //char msg[] = "MFAIL=0\n";
  //msg[6] = '0'+symptom;
  //usart_write(msg,8);
  usart_msg("MFAIL=");
  usart_writechar('0'+symptom);
  usart_writechar('\n');
}

void EVENT_door_locked(bool success) {
  do_pinpad_feedback(success?5:0);
  print_door_feedback(1,success?1:0);
}

void EVENT_door_unlocked(bool success) {
  do_pinpad_feedback(success?4:1);
  print_door_feedback(2,success?1:0);
}

void EVENT_door_mode_changed(uint8_t old_mode) {
  dequeue_events(&report_state_event);
  enqueue_event_rel(DOOR_REPORT_DELAY,&report_state_event,NULL);
}


void startup() {
  // disable watchdog if enabled
  wdt_reset();
  MCUSR &= ~(1 << WDRF);
  wdt_disable ();

  // disable any output, just in case
  DDRB = 0;
  DDRC = 0;
  DDRD = 0;
  // enable pullups
  PORTB = 0xff;
  PORTC = 0xff;
  PORTD = 0xff;

  // configure pins
  PORTB &= ~(1<<ledpin);
  DDRB |= 1<<ledpin;

  //adc_conf(true,0,7); // enable, no adc pins, slow prescaler
  // spec says 50..200kHz for accuracy, we have 16M for cpu, need factor 2^7.

  // setup event processing
  events_start(TIMER_SCALE);

  usart_init();
  buttons_init();
  door_init();

  adc_conf(true,0,ADC_DIV_128); // pins C3, ADC6 and ADC7
  adc_watch_init(0);
  pinpad_init();

/*
  NONATOMIC_BLOCK(NONATOMIC_FORCEOFF) {
    eepromfs_index(&eep_index,0,0);
  }
*/

#ifdef DEBUG_DISPLAY
  display_init();
#endif
  adc_watch_start();

  load_state();
}

int main() {

  startup();
  prng_seed(0);
  //application_start(0); // starts default application (menu).

  sei();


  // prepare for sleeping
  set_sleep_mode(SLEEP_MODE_IDLE);
   // _ADC, _PWR_DOWN, _PWR_SAVE, _STANDBY, _EXT_STANDBY
   // PWR_SAVE leaves Timer2 active, PWR_DOWN is rather off.
  while(true) {
    // let the ISRs handle the events.
    sleep_mode();
      /* or:
           sleep_enable(); sei(); sleep_cpu(); sleep_disable();
         for avoiding race conditions we don't have.
      */
  }
  return 0;
}

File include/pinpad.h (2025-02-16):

/*

  Custom pinpad driver. Consumes 1 pin on Port C.

  Copyright (c) 2019 Thomas Kremer

*/

/*
 * This program is free software; you can redistribute it and/or modify it
 * under the terms of the GNU General Public License version 2 or 3 as
 * published by the Free Software Foundation.
 */

#ifndef __PINPAD_H__
#define __PINPAD_H__

/*
  This is the common implementation to read a pressed key on the pinpad pin.
  

  Requirements: 
    * A pin with both ADC and interrupt capability (C0..C5).
    * Choose one of the surrported pinpad models by defining
      PINPAD_IMPLEMENTATION to LINEAR or MATRIX            

  internal wiring:
    We used C = 2*220nF, Dz = 12V Zener diode, soldered everything directly
    between two pin headers (everything in SMD parts except for Dz).

  # S1: Adc Conection to Arduino input pin:

    VCC -----+
             Ru
             +-------+--- *K+
             Rm      |
    MC_adc---+      ^Dz
             C       |
             +-------+--- *K-
             Rd
    GND-*----+

    Chosen Values:
      R_u = 10k 
      R_d = 1k
      R_m can be ignored as there is no current flowing over the ADC
      R_k(i) = chosen in pinpad_matrix.h or pinpad_linear.h
      The pinpad adc value at the MC pin can be calculated with the formula:
      MC_adc(i) = 1024 * (R_k(i) + R_u) / (R_k(i) + R_ud)

    Derived Values:
      The adc of our arduino has 10bit Resolution.
      Adc_range = 2^10 = 1024
      Adc_max = 2^10 - 1 = 1023
*/

// every implementation of a pipad needs the function get_pinpad_key and the value pinpad_min_idle
#ifdef PINPAD_LINEAR
#include "pinpad_linear.h"
#else
#ifdef PINPAD_MATRIX
#include "pinpad_matrix.h"
#else
#error "PINPAD_IMPLEMENTATION was not set"
#endif
#endif
#include <adc_watch.h>

/* This needs to be done elsewhere:
void EVENT_adc_watch(uint8_t channel, int16_t value) {
  if (channel == PINPAD_PIN)
    pinpad_on_adc_read(value);
}
void init() {
  PCICR |= 1<<PCIE1;
}
*/

// Port is always C
#ifndef PINPAD_PIN
#define PINPAD_PIN 0 // C0, ADC0
#endif // PINPAD_PIN


/// @brief Pinpad context to trac the currently monitored value
typedef struct
{
  int16_t minval;
} pinpad_ctx_t;
pinpad_ctx_t pinpad_ctx;

void EVENT_pinpad_keypressed(char c);
bool snprintl(char *s, int len, int32_t value);
/**
 * @brief pressing a key i means going down to a voltage that is within
 *        pinpad_adc_values[i], then going up again.
 * @param value todo
 */
void pinpad_on_adc_read(int16_t value)
{
  // Get the tracked value
  int16_t minval = pinpad_ctx.minval;
  // Was the value reset then start a new measurement with the current value
  if (minval == 1024)
  {
    // TODO:
    adc_watch_set_range(PINPAD_PIN, value - 5, value + 5);
  }
  // Update the tracked value if the value if it is lower
  if (value < minval)
  {
    minval = value;
    pinpad_ctx.minval = minval;
  }
  // Once the key has been released
  if (value > pinpad_min_idle)
  {
    char key = get_pinpad_key(minval);
    if(key != '\0'){
        EVENT_pinpad_keypressed(key);
    }
    // Reset traced value and adc watch range
    pinpad_ctx.minval = 1024;
    adc_watch_set_range(PINPAD_PIN, pinpad_max_valid, 1023);
  }
}

void pinpad_sleep()
{
  // need to activate digital input, disable reading
  uint8_t mask = (1 << PINPAD_PIN);
  PCMSK1 |= mask;
  DIDR0 &= ~mask;
  adc_watch_set_mask(adcw_state.mask & ~mask);
  // adc_watch_set_range(PINPAD_PIN,0,1023);
}

void pinpad_unsleep()
{
  // need to disable digital input, activate reading
  uint8_t mask = (1 << PINPAD_PIN);
  PCMSK1 &= ~mask;
  DIDR0 |= mask;

  adc_watch_set_range(PINPAD_PIN, pinpad_max_valid, 1023);
  adc_watch_set_mask(adcw_state.mask | mask);
}

void pinpad_init()
{
  pinpad_ctx.minval = 1024;
  DDRC &= ~(1 << PINPAD_PIN);
  PORTC &= ~(1 << PINPAD_PIN);
  // PORTC |= (1<<PINPAD_PIN);
  pinpad_unsleep();
}

void pinpad_stop()
{
  pinpad_sleep();
  pinpad_ctx.minval = 1024;
  PORTC |= (1 << PINPAD_PIN); // enable internal pull-up, just in case.
}

#endif

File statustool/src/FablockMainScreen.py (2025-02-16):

import tkinter as tk
from tkinter import messagebox
from serial_comm import SerialComm
from messages import parse_message

import logging

logging.basicConfig(level=logging.INFO, format="%(asctime)s [%(levelname)s]: %(message)s")

class FablockMainScreen:
    def __init__(self, root, serial_comm):
        self.root = root
        self.serial_comm = serial_comm
        self.setup_ui()

    def setup_ui(self):
        self.status_label = tk.Label(self.root, text="Status: Offline", font=("Arial", 12))
        self.status_label.pack(pady=5)

        # Grouping related labels into a frame
        status_frame = tk.Frame(self.root, borderwidth=5, relief="groove")
        status_frame.pack(pady=5)

        

        
        self.door_status_label = tk.Label(status_frame, text="Door: Unknown", font=("Arial", 12))
        self.door_status_label.pack(pady=5)

        self.awake_status_label = tk.Label(status_frame, text="Awake: reset", font=("Arial", 12))
        self.awake_status_label.pack(pady=5)

        self.pin_status_label = tk.Label(status_frame, text="PIN: Unknown", font=("Arial", 12))
        self.pin_status_label.pack(pady=5)

        self.sense_status_label = tk.Label(status_frame, text="Motor ADC: Unknown", font=("Arial", 12))
        self.sense_status_label.pack(pady=5)

        # Grouping related labels into a frame
        connect_frame = tk.Frame(self.root, borderwidth=5, relief="sunken")
        connect_frame.pack(pady=5)

        self.connect_button = tk.Button(connect_frame, text="Connect", command=self.connect_serial, font=("Arial", 12))
        self.connect_button.pack(pady=10)

        self.disconnect_button = tk.Button(connect_frame, text="Disconnect", command=self.disconnect_serial, font=("Arial", 12), state=tk.DISABLED)
        self.disconnect_button.pack(pady=10)

        command_frame = tk.Frame(self.root, borderwidth=5, relief="solid")
        command_frame.pack(pady=5)

        self.open_button = tk.Button(command_frame, text="Open", command=self.open_command, font=("Arial", 12))
        self.open_button.pack(pady=10)

        self.close_button = tk.Button(command_frame, text="Close", command=self.close_command, font=("Arial", 12))
        self.close_button.pack(pady=10)


    # Callback to update the GUI with parsed messages
    def update_status(self,message):
        if len(message) == 0:
            return
        
        parsed_data = parse_message(message)
        if not parsed_data:
            logging.info(f"'{message}' with len {len(message)} was not parsed")
            return
        logging.debug(parsed_data)
        if parsed_data["type"] == "DOOR":
            self.door_status_label.config(
                text=f"Door: {parsed_data['locked']}, {parsed_data['closed']}, "
                    f"{parsed_data['motor_state']}, Action: {parsed_data['motor_action']}"
            )
        elif parsed_data["type"] == "AWAKE":
            self.awake_status_label.config(text=f"Awake: {parsed_data['awake']}")
        elif parsed_data["type"] == "PIN":
            self.pin_status_label.config(text=f"PIN: {parsed_data['value']}")
        elif parsed_data["type"] == "SENSE":
            self.sense_status_label.config(text=f"Motor ADC: {parsed_data['value']}")
        elif parsed_data["type"] == "OK":
            pass
        else:
            logging.info(f"Message type {parsed_data['type']} was not evaluated")

    # Connect button functionality
    def connect_serial(self):
        try:
            self.serial_comm.connect()
            self.serial_comm.set_callback(self.update_status)
            self.connect_button.config(state=tk.DISABLED)
            self.disconnect_button.config(state=tk.NORMAL)
            self.status_label.config(text="Connected to Serial Port")
        except Exception as e:
            logging.error("Open the serial connection failed:" +str(e))

    # Disconnect button functionality
    def disconnect_serial(self):
        try:
            self.serial_comm.disconnect()
            self.connect_button.config(state=tk.NORMAL)
            self.disconnect_button.config(state=tk.DISABLED)
            self.status_label.config(text="Disconnected from Serial Port")
        except Exception as e:
            logging.error("Closing the serial connection failed:" +str(e))

    # Open button functionality
    def open_command(self):
        try:
            self.serial_comm.send_command("!D1\r")
            self.status_label.config(text="Open Command Sent (!D1)")
        except Exception as e:
            logging.error("Sending open command failed:" +str(e))

    # Close button functionality
    def close_command(self):
        try:
            self.serial_comm.send_command("!D0\r")
            self.status_label.config(text="Close Command Sent (!D0)")
        except Exception as e:
            logging.error("Sending close command failed:" +str(e))

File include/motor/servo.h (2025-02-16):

/*

  servo.h - control 1 servo using bit-banging with the event subsystem.

  Copyright (c) 2019 Thomas Kremer

*/

/*
 * This program is free software; you can redistribute it and/or modify it
 * under the terms of the GNU General Public License version 2 or 3 as
 * published by the Free Software Foundation.
 */

#ifndef _MOTOR_SERVO_H__
#define _MOTOR_SERVO_H__
// data sheet:
//#define servo_pulse_low msec2ticks(1,TIMER_DIV)
//#define servo_pulse_high msec2ticks(2,TIMER_DIV)

// To test actual limits:
//#define servo_pulse_low msec2ticks(0.1,TIMER_DIV)
//#define servo_pulse_high msec2ticks(12.8,TIMER_DIV)

// tested results:
// correct range: 0.6 - 2.35 0.6..2.25 = 180°
#define servo_pulse_low msec2ticks(0.6,TIMER_DIV)
//miscalculation: #define servo_pulse_high msec2ticks(2.7,TIMER_DIV)
#define servo_pulse_high msec2ticks(2.35,TIMER_DIV)
#define servo_total_angle (180L*(235-60)/(225-60))
// 0.6 + 216/255*(2.7-0.6) = 216/255*2.1 = 2.38
#define servo_pwm_period msec2ticks(20,TIMER_DIV)

// TODO: Port hardcoded to Port C

#ifndef SERVO_PIN
#warning(Choosing default value for SERVO_PIN)
#define SERVO_PIN 5
#endif


//uint8_t servo_pos = 128;
//uint8_t servo_step = 1;
int32_t servo_pulse = (servo_pulse_low+servo_pulse_high)/2;

void door_set_motor(uint8_t dir) {
  if (dir < 3) {
    if (dir == 0) {
      // disable motor
      servo_stop();
    } else {
      // set direction pin
      if (dir == 2)
        servo_set_pos(0);
      else
        servo_set_pos(255);
      // enable motor and run it.
      // TODO: should we really make a servo_maybe_start()?
      // TODO: should we really rely on servo_stop() to be idempotent?
      servo_stop();
      servo_start();
    }
  }
}

void servo_ontimer(void* param) {
  uint16_t val = (uint16_t)param;
  int32_t interv = 0;
  if (val == 0) {
    PORTC |= 1<<SERVO_PIN;
    interv = servo_pulse;
    val = 1;
  } else {
    PORTC &= ~(1<<SERVO_PIN);
    interv = servo_pwm_period - servo_pulse;
    val = 0;
  }
  enqueue_event_rel(interv,&servo_ontimer,(void*)val);
}

void servo_set_pos(uint8_t servo_pos)
{
  servo_pulse = servo_pulse_low + (((int32_t)servo_pos)*(servo_pulse_high-servo_pulse_low))/255; // going from -1 to 2 instead of 0 to 1. // /255;
  //servo_pulse = servo_pulse_low + (((int32_t)servo_pos - 64)*2*(servo_pulse_high-servo_pulse_low))/255; // going from -1 to 2 instead of 0 to 1. // /255;
}

void door_motor_init() {
  servo_set_pos(128); // middle
}

void servo_start() {
  PORTC &= ~(1<<SERVO_PIN);
  DDRC |= 1<<SERVO_PIN;
  servo_ontimer(NULL);
}
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

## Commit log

2019-07-03 lockserver: added cron object to manage device pings and other timed stuff.
2019-07-09 hardware spec was missing door sensors; script to generate password file.
2019-07-11 symlinks were still wrong.
    [adc_watch.h, pinpad.h]
2019-07-11 updated hardware spec to include debouncing capacitors.
2019-07-13 added CAD files for pinpad casing.
    [box.stl, lid.stl, pinpad-case.scad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]
2019-07-22 added check in lockserver to reset device if input is not working.
2019-07-23 Revert "disabled pinpad sleep mode for debugging."
    This reverts commit 2bc045fcede5df13ad0b46f8b94041eaa73118f0.
    [main.c]
2019-07-23 corrected pinpad pin designation in hardware spec.
2019-07-28 add time command to check for after reset.
    [main.c]
2019-07-28 Check device time after reset. For now, only debug-logged.
2020-12-03 lockserver-audio: wait for motor to start before playing goodbye-sound.
2023-04-28 Adapted servo voltages to demo board
2023-04-29 Stall still doesnt work
    [door.h]
2023-09-18 Current Version
2023-10-09 Added hardware fail resolver + fintunings for servordoor
    [door.h]
2023-10-15 Added back old servo code
2025-02-16 Add configuration for Stepperdrivers
2025-02-16 Cleanup Motor
2025-02-16 Created flowchart for door.h
